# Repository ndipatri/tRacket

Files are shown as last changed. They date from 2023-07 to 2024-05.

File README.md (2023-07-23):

# tRacket

## tRacket is a mobile network-enabled device meant to be installed at a tennis court so you can know when a court is available by looking at a Twitter feed.

This outer project also involves a Kotlin Multi Platform (KMP) solution to provide mobile code for both iOS and Android.  I've recently decided that using Twitter to access live tRacket information is better.. So most of my work now on this project is inside of this subdirectory of this Github Project:

[tRacket Device Project](https://github.com/ndipatri/tRacket/blob/main/particle/workbench/tRacket/README.md)

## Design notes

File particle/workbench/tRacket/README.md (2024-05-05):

# tRacket - Tennis Court Occupancy Tracker

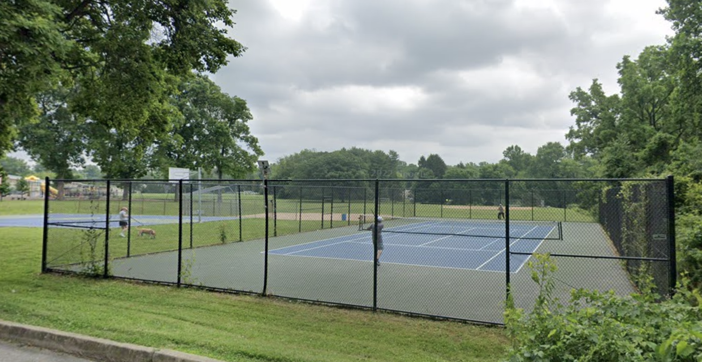
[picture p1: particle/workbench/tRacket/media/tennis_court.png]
tRacket Tennis Court


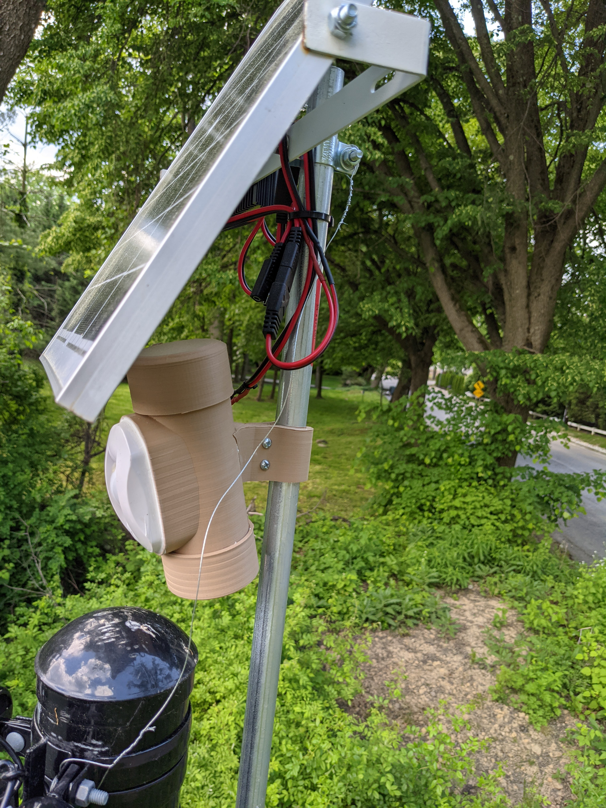
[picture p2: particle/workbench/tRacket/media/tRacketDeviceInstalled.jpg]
tRacket Device Installed


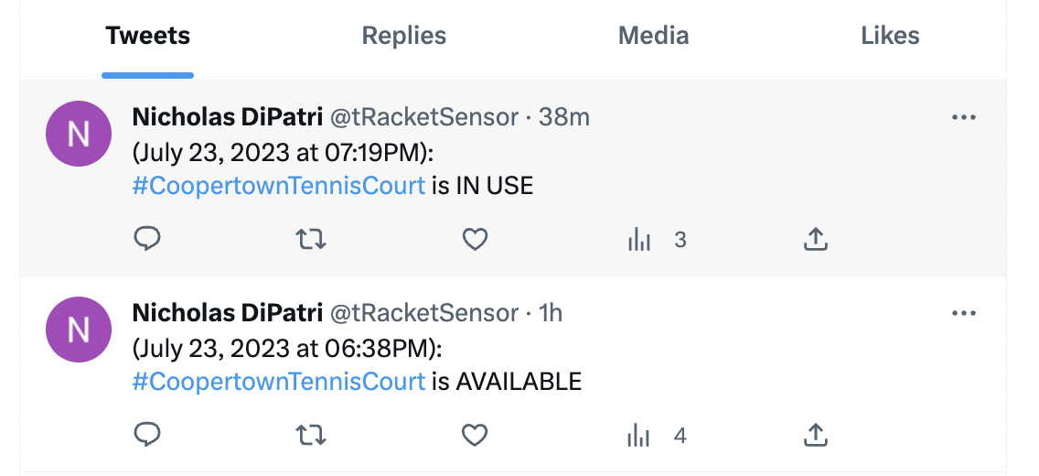
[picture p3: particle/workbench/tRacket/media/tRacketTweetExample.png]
tRacket Tweet Example


This is the Particle Workbench project that contains the code for the courtside tRacket device itself. 

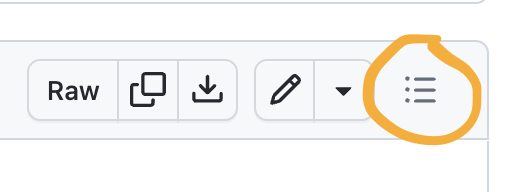
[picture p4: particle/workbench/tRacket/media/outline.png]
Turn on Outline View
I recommend viewing this README with 'Outline' view turned on: 

## Architecture

There are three main components to the tRacket system: the tRacket courtside device, an MQTT Broker provided by [Adafruit.io](https://io.adafruit.com/), and an Applet on the [If This Than That (IFTTT)](https://ifttt.com/) Integration Server.

The result is whenever the tRacket device detects the beginning or ending of court occupation, a Tweet is sent.

### tRacket courtside device

The tRacket [Particle](https://www.particle.io/devices/) microcontroller-based courtside device has an LTE wireless radio and can establish an MQTT connection to [Adafruit.io](https://io.adafruit.com/).  Whenever there is a change in occupancy on the court, a message is sent from the tRacket device in this format:

`2023/07/23 05:57:54PM	CoopertownElementary:1`

With a pattern of: |dateTime|tRacketID|:|Occupancy, 1-Occuped, 0-Available|

The tRacket device has a custom 12-volt NiHM battery pack that is charged by a solar panel (as shown in picture above).

### Adafruit.io MQTT Broker

[Adafruit.io](https://io.adafruit.com/) has a $10/month subscription service for devices that need to push data up to the cloud for asynchronous access.  Given the tRacket device is powered by solar and its only network connection is a very cheap LTE radio, we don't want end-consumers to connect directly to the tRacket device.  The Adafruit MQTT Broker is a perfect intermediary.

The tRacket device pushes data up to the 'occupancy' and 'recharge' MQTT topics.  When you push up to Adafruit.io, the topics or 'feeds' are created dynamically. So there is very little you need to configure on Adafruit.io for this to all work.

The 'occupancy' feed contains the occupancy data described previously.  The 'recharge' feed contains a message if the tRacket device gets low on power.  This would be useful for identifying if the solar panels are no longer charging the batteries affectively. 

**My single tRacket device has been running on solar power with no problems for over two years as of July 2023.**

### If This Than That (IFTTT) Integration Server

If This Than That (IFTTT) Integration Service ($60/yr for 'Pro' plan) monitors the Adafruit.io 'occupancy' feed and delivers a message to the [tRacketSensor Twitter Handle](https://twitter.com/tRacketSensor).  Here is an example message:

tRacket Tweet Example

From the above Tweet history, we can see that the court was occupied but then became available on July 23, 2023 at 06:38PM.  It remained available for 41 minutes until it became occupied again at 07:19PM.

My IFTTT account has been configured with two Applets.  The first detects a change in the Adafruit.io 'occupancy' feed and then passes that data in a webhook back to the second Applet which responds by formulating the above message and posting a Tweet.

Configuring these two Applets is rather tedious and involves the following details:

#### Two Applets are needed. ####

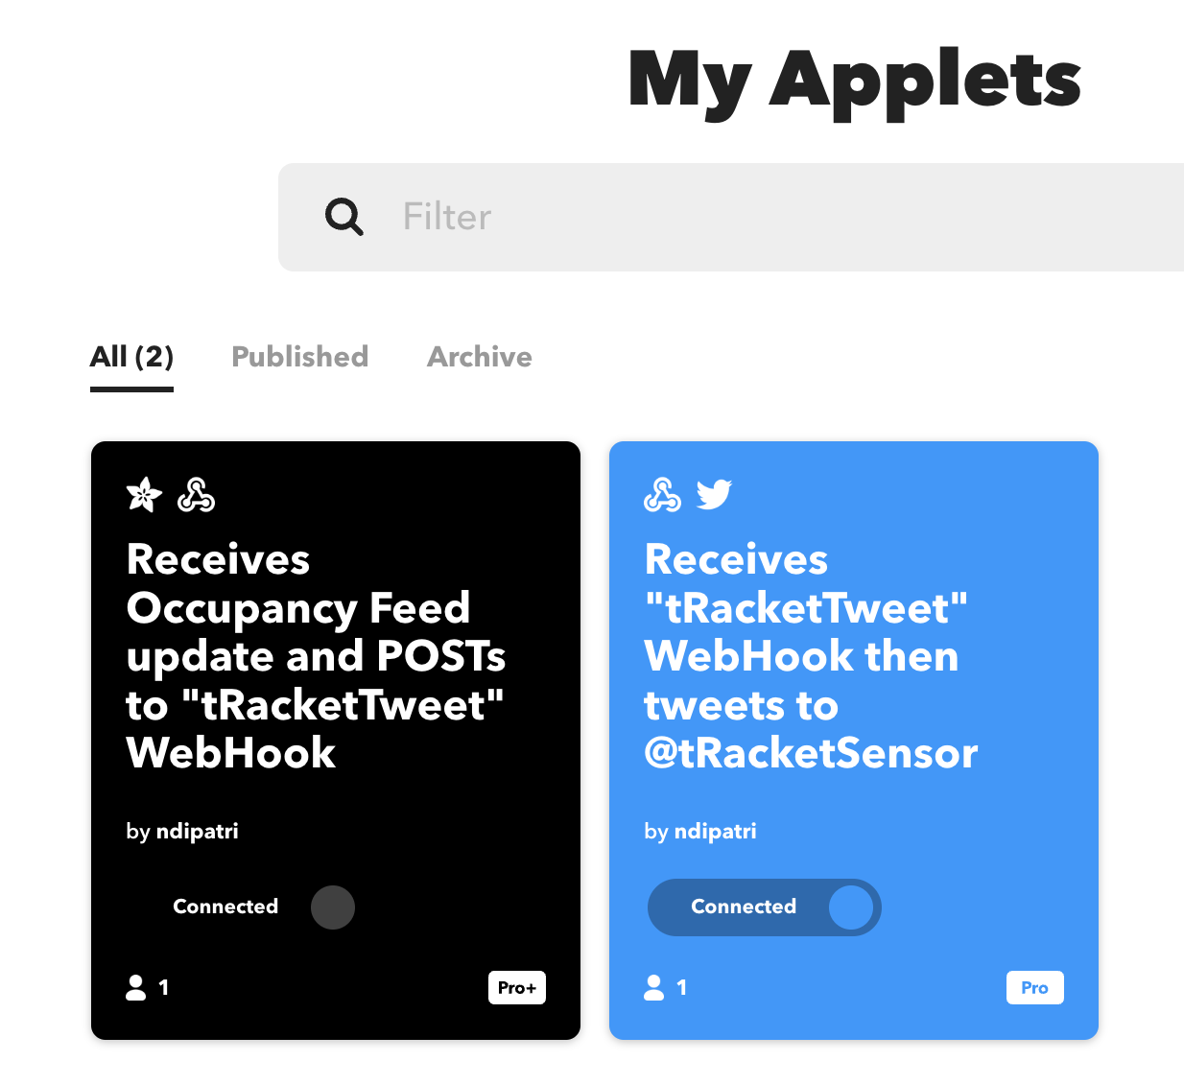
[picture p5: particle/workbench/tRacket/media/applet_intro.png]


#### First Applet ####

'Receives Occupancy Feed update and POSTs to "tRacketTweet" WebHook'

##### First Applet requires four steps: #####

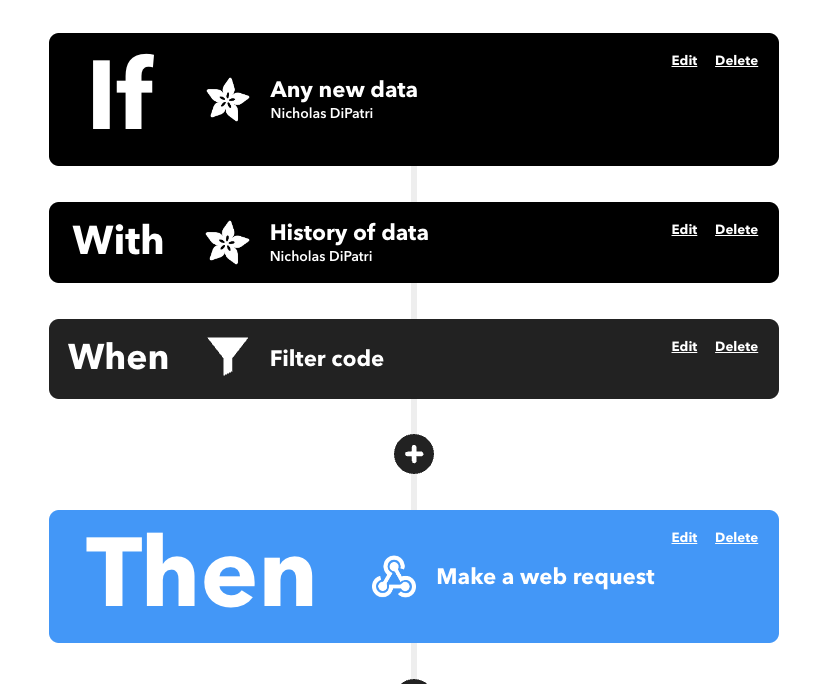
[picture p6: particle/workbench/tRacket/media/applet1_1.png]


###### First Applet, First Step. If: 'Any new data' #####

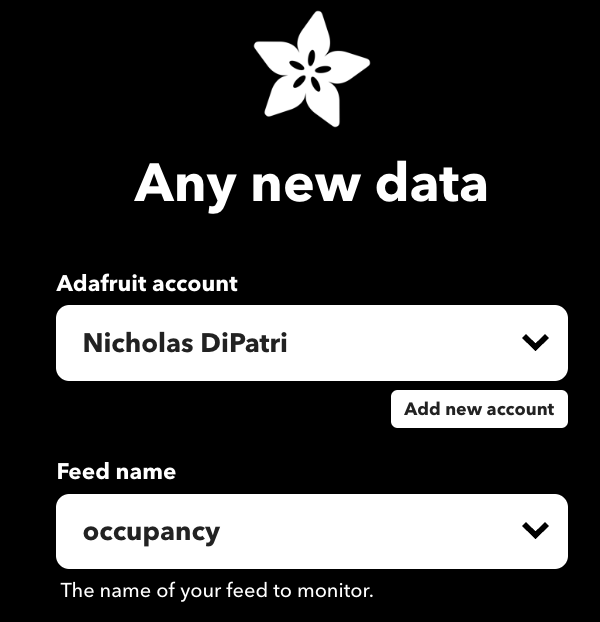
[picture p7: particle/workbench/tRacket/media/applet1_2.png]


###### First Applet, Second Step. With: 'History of data' ######

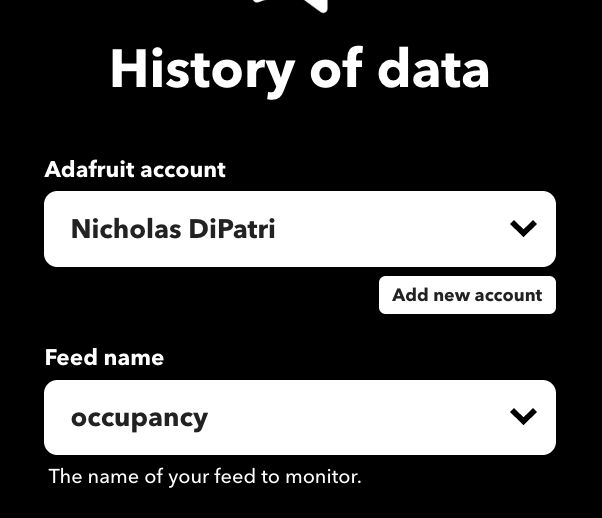
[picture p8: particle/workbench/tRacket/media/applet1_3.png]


###### First Applet, Third Step. When: 'Filter code' ######

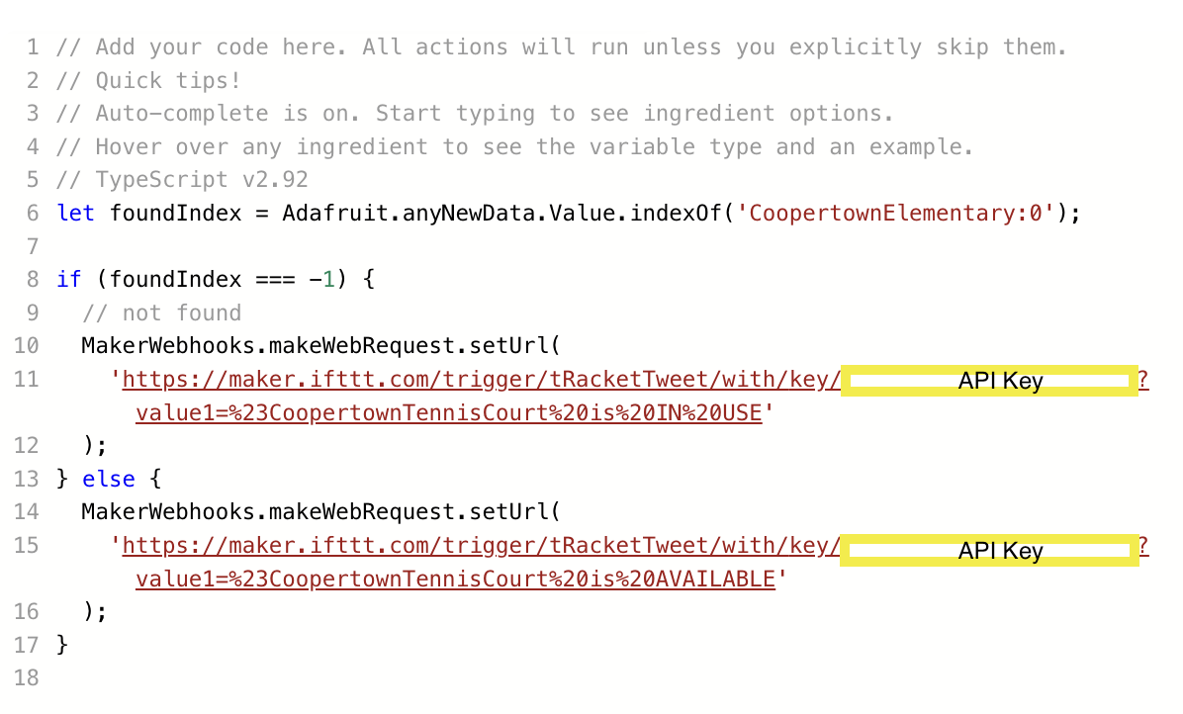
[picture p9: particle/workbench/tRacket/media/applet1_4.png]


###### First Applet, Fourth Step. Then: 'Make a web request' ######

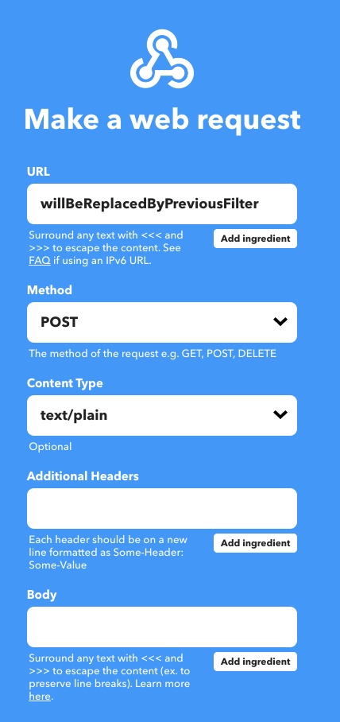
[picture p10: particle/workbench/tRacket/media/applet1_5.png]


#### Second Applet ####

'Receives "tRacketTweet" WebHook then tweets to @tRacketSensor'

##### Second Applet requires two steps: #####

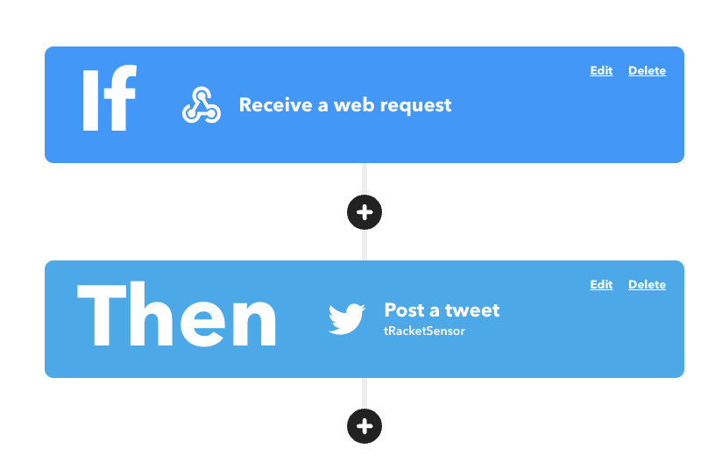
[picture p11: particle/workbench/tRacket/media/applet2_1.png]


###### Second Applet. First Step. If: 'Receive a web request' #####

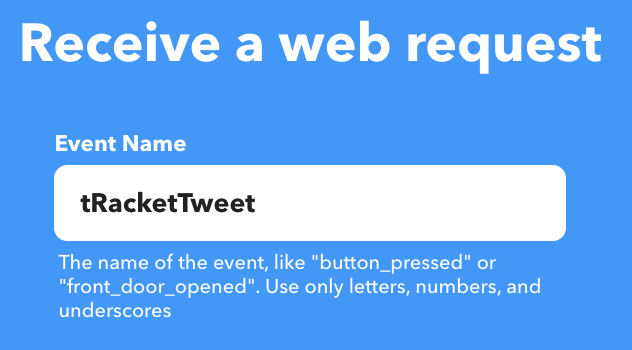
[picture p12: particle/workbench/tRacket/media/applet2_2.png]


###### Second Applet. Second Step. Then: 'Post a Tweet' ######

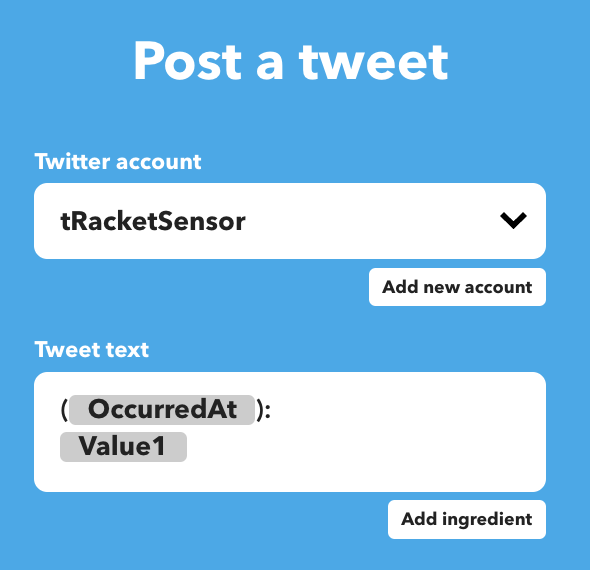
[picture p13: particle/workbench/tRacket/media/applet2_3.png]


### Parts List ###

#### 12V Solar Panel with Charging Circuit ####
I used a [Solar Panel kit](https://www.amazon.com/gp/product/B08GX19KT9/ref=ppx_yo_dt_b_search_asin_title?ie=UTF8&psc=1).  The charging terminals from the solar panel attach directly across the 12v NiMH battery pack. (+ to +, - to -)

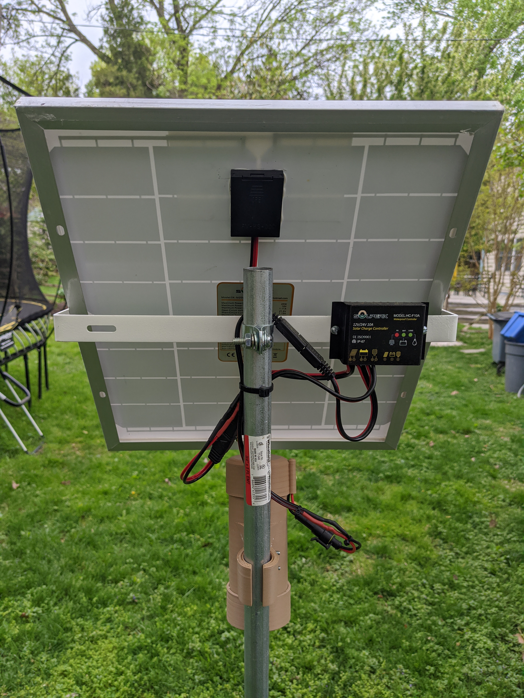
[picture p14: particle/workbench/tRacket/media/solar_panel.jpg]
solar panel


#### Rechargeable Battery Pack ####

The battery pack is custom built from [10 1.2V 2800mAH NiHM batteries](https://www.amazon.com/gp/product/B07PJZKB8X/ref=ppx_yo_dt_b_search_asin_title?ie=UTF8&psc=1).  They are soldered in series. 8 are in one pack and 2 are in another.  This arrangement was made to be able to fit the batteries most efficiently in the 3D enclosure. The 2-pack fit under the circuit board. Lots of electrical tape is used to prevent shorts anywhere.

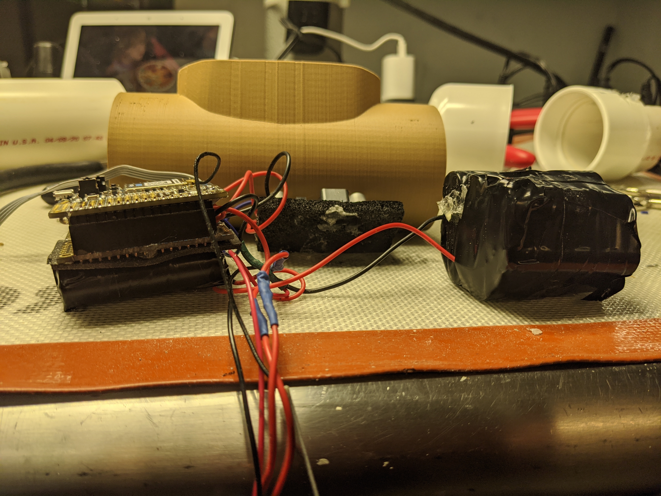
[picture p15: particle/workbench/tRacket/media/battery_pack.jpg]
battery pack


#### DC-DC Buck Converter ####

The [DC-DC Buck Converter](https://www.amazon.com/Adjustable-Converter-1-5-35v-Efficiency-Regulator/dp/B07C2QF1T1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) is what converts our 12V battery to 3.7V for the micro-controller.  It has a micro-potentiometer that is used to manually adjust down the Vout.

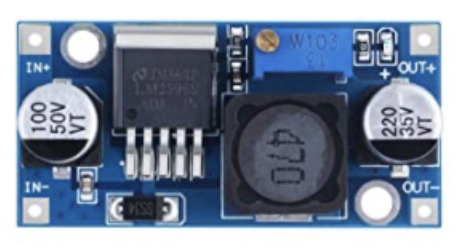
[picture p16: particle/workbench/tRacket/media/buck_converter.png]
buck converter


#### Particle Boron MicroController ####

The [Boron](https://www.amazon.com/PARTICLE-Development-Endpoints-Circuitry-Bluetooth/dp/B07N96P69L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) is a Arduino-based Microcontroller with LTE cellular network connectivity.

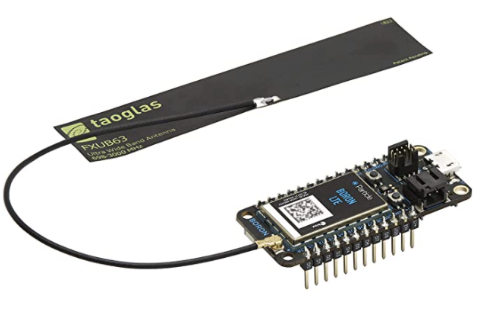
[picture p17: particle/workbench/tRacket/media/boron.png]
Boron Microcontroller


The [tRacket.ino](src/tRacket.ino) file can be used to program the Particle Boron.  You will need to create your own [Secrets.h](src/Secrets.h) file which contains the following content:

```
#ifndef SECRETS_H
#define SECRETS_H

// If you check in this code WITH this KEY defined, it will be detected by IO.Adafruit
// and IT WILL BE DISABLED!!!  So please make sure this file is 'ignored' by your
// source code management!
#define AIO_USERNAME "xxxxxx"
#define AIO_KEY "aio_xxxxx"
#define AIO_SERVER      "io.adafruit.com"
#define AIO_SERVERPORT  1883          // use 8883 for SSL

#endif
```

#### Motion Sensor (Brojen BJ-912)  ####

The [Brojen BJ-912](https://www.amazon.com/BROJEN-Brojen-BJ-912-Curtain/dp/B07C53ZS2Y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) motion sensor is placed directly inside the 3D enclosure.  This sensor requires 12V which is why we have a 12V supply. The reason I use this motion sensor device unmodified is so anyone on the court will readily identify tRacket as simply a motion sensor and not something more invasive like a camera or microphone.

Changes need to be made on the inside of the motion sensor. The 'Normally Open (NO)' jumper needs to be ~~removed~~ (jumper should now remain in the 'Normally Closed (NC)' position) and the 'LED ON' (i.e. 'Enable LED') jumper wires need to be brought outside of the sensor as shown.  The 'Enable LED' signal is set by the microcontroller as the LED is enabled when the tRacket is in 'test' mode.  This is so under normal operation, the LED is turned off.

The motion sensor should be sealed into the main 3D enclosure with exterior silicon-based caulk.  It's important to make this a waterproof seal.

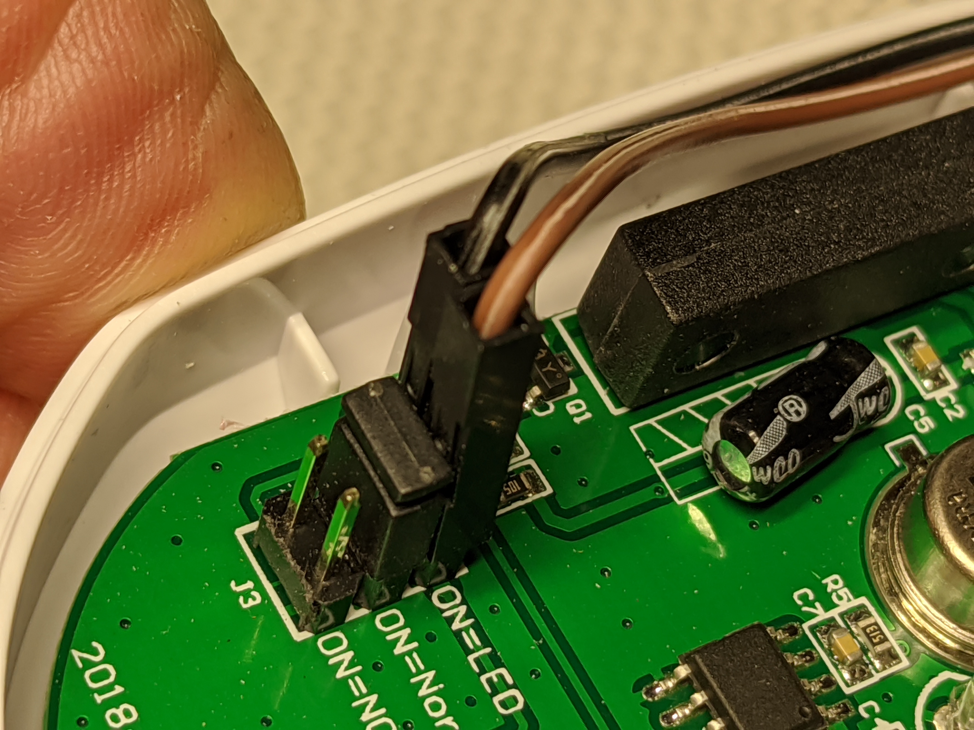
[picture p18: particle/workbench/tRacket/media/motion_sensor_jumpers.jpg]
Motion Sensor Jumpers


The 'Enable LED' signal is connected to the external bus on the motion sensor as shown:

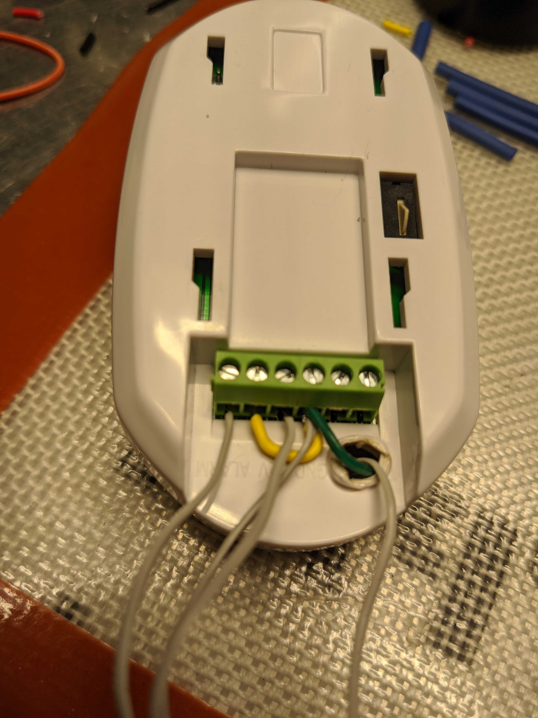
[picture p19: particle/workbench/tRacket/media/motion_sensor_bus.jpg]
Motion Sensor Bus


#### Featherwing Doubler ####

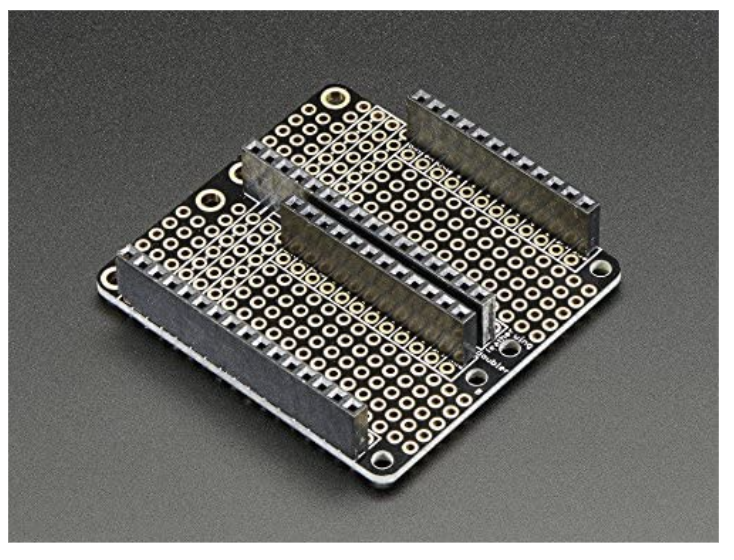
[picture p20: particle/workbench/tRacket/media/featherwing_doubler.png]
Featherwing Doubler


[Featherwing]((https://www.adafruit.com/product/2890)) is a standard for wiring up microcontrollers and peripherals.  Certain connections are common across all three sockets.  The VBAT pin has a max rating of 3.7V.  

#### Current Meter ####

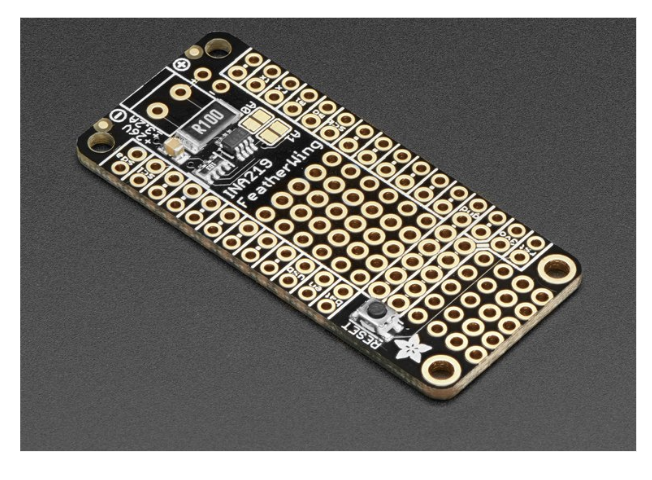
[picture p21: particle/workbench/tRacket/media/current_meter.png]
Current Meter


We use the [Adafruit INA219 FeatherWing Current Meter](https://learn.adafruit.com/adafruit-ina219-current-sensor-breakout) to warn us when the 12V battery needs to be recharged. 

This comes in the Featherwing form-factor so it fits on the above Featherwing Doubler along with the Particle microcontroller. It also has a small ‘experiment’ area onto which I install a transistor to drive the motion sensor.

We currently report one of two states: ‘RECHARGE’ or ‘GOOD’.  We employ a Schmitt Trigger to determine which state we are in.  This requires two voltage thresholds:  a low (12.2 VDC) and a high (12.6 VDC). This avoids ‘oscillating’ that might happen if the voltage were to hover around a single threshold (e.g. RECHARGE, GOOD, RECHARGE, GOOD, etc.) 

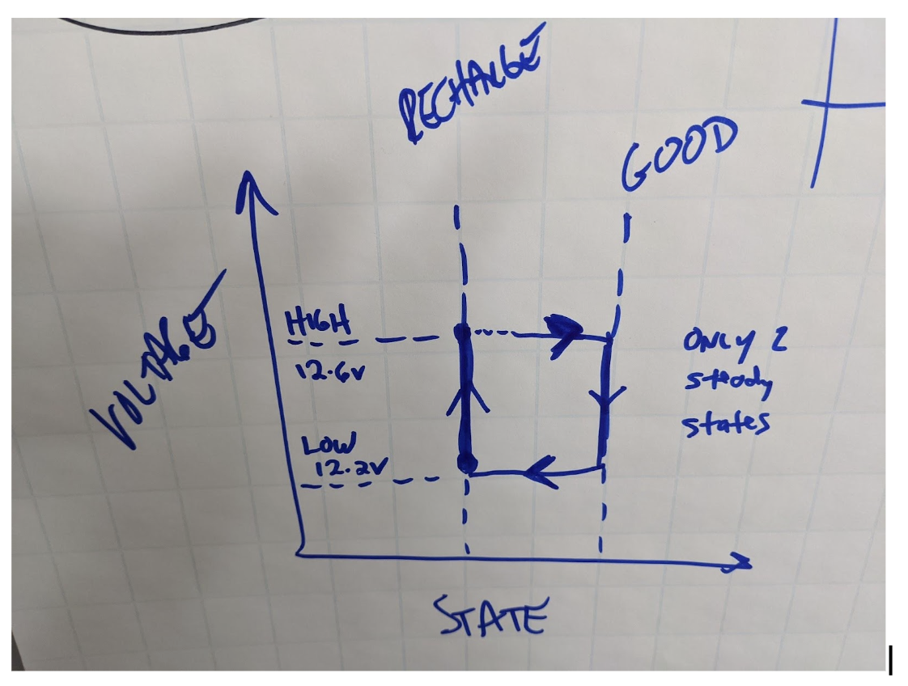
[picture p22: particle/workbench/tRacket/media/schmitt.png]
Schmitt Trigger


#### Schematic ####

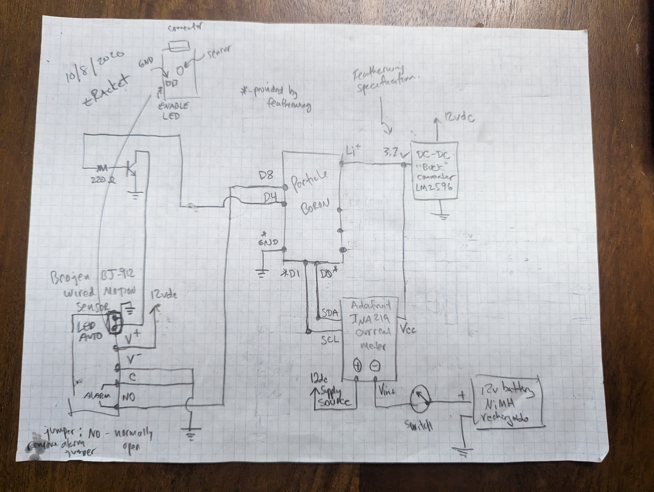
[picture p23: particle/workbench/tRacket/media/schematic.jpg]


### 3D STL Files ###

The tRacket device is built using 3D-printed parts. The tRacket device is mounted to a pole with a 3D-printed bracket.  The pole is mounted to a typical tennis court using stainless-steel band clamps.

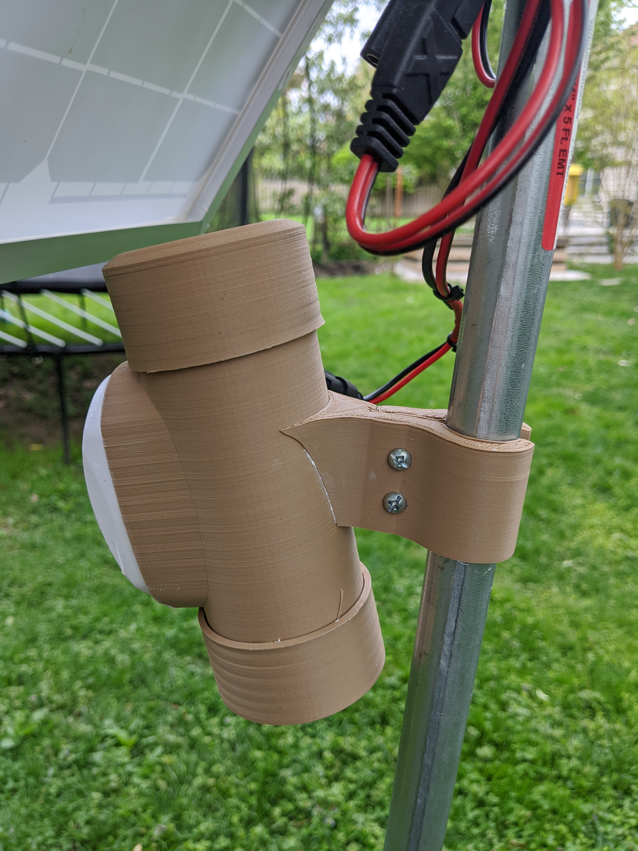
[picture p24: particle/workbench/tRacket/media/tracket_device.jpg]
tRacket Device


pole mount

[Main Body](3d_prints/tRacket_mainBody.stl)

[Body Mount Left](3d_prints/tRacket_bodyMount1.stl)

[Body Mount Right](3d_prints/tRacket_bodyMount2.stl)

[Bottom Cap](3d_prints/tRacket_bottomCap.stl)

[Top Cap](3d_prints/tRacket_topCap.stl)

[Internal Tray](3d_prints/tRacket_tray.stl)

### Assembly Instructions ###

All seals should be secured with exterior grade silicon-based caulk.  The following pictures are meant to provide guidance on how to assemble tRacket parts.

Assembly 1

Assembly 2

Assembly 3

Assembly 4

Assembly 5

Assembly 6

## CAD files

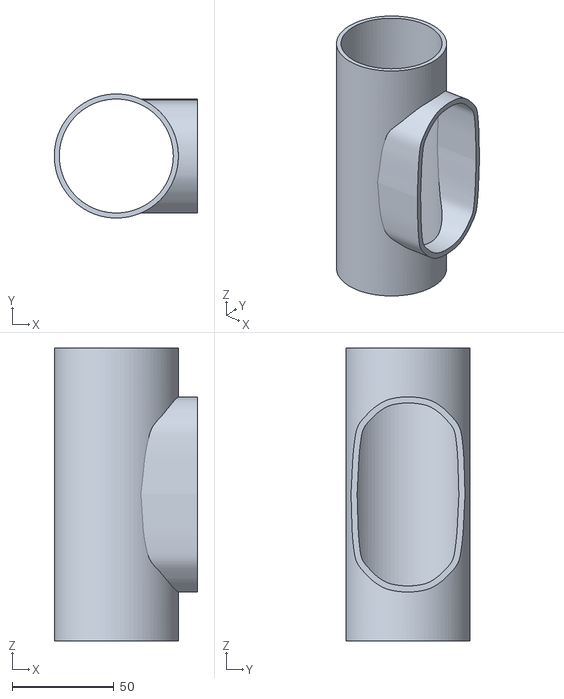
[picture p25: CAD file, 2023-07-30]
particle/workbench/tRacket/3d_prints/tRacket_mainBody.stl
70.5 x 61.0 x 144.0

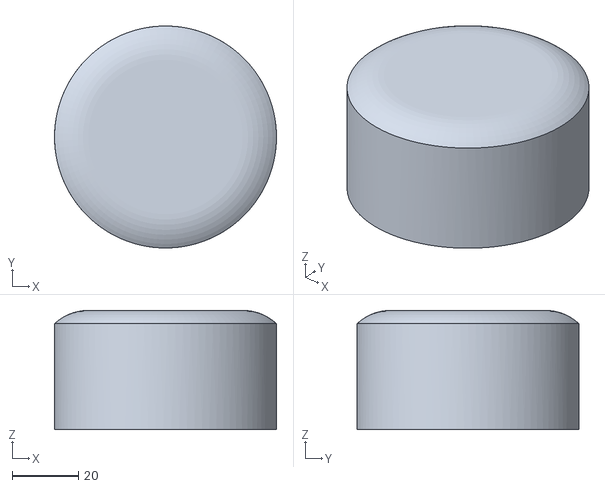
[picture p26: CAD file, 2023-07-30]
particle/workbench/tRacket/3d_prints/tRacket_bottomCap.stl
67.0 x 67.0 x 36.0

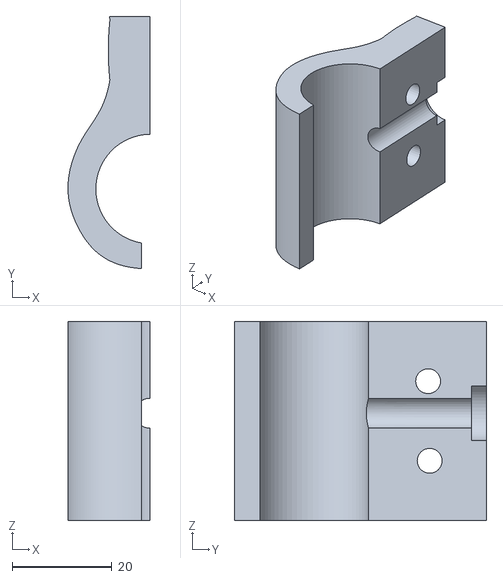
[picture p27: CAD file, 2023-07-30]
particle/workbench/tRacket/3d_prints/tRacket_bodyMount1.stl
16.5 x 50.7 x 40.0

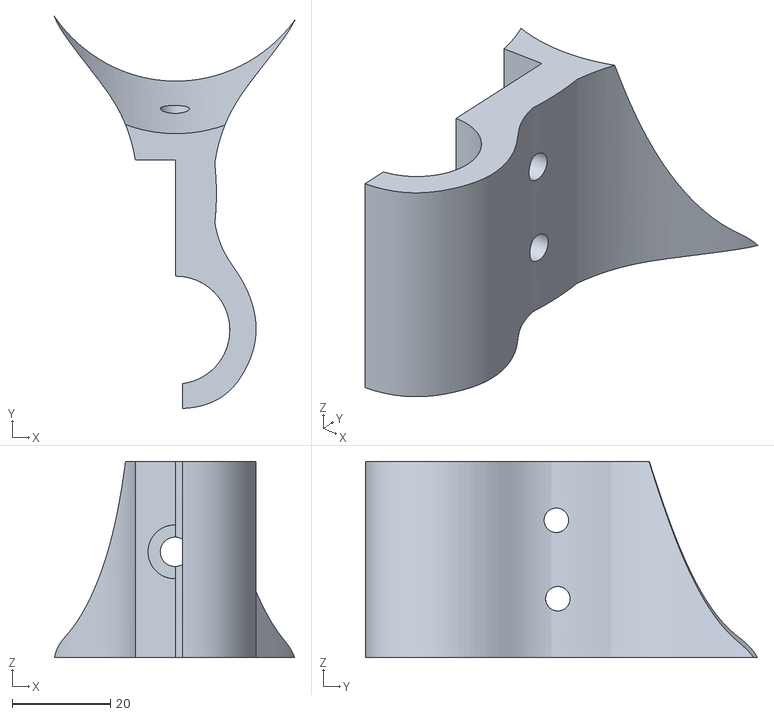
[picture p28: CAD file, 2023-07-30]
particle/workbench/tRacket/3d_prints/tRacket_bodyMount2.stl
49.0 x 80.0 x 40.0

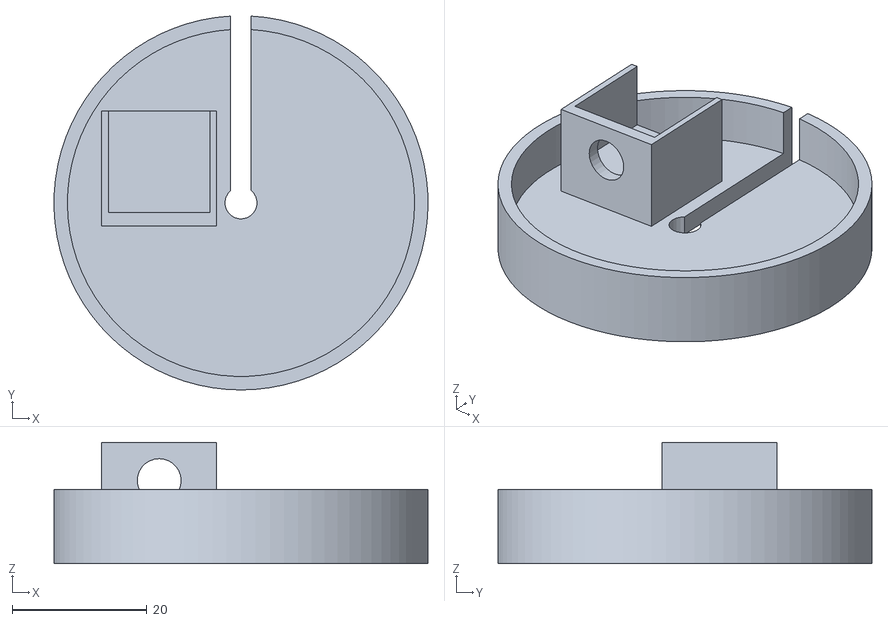
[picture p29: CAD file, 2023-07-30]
particle/workbench/tRacket/3d_prints/tRacket_tray.stl
55.5 x 55.5 x 18.0

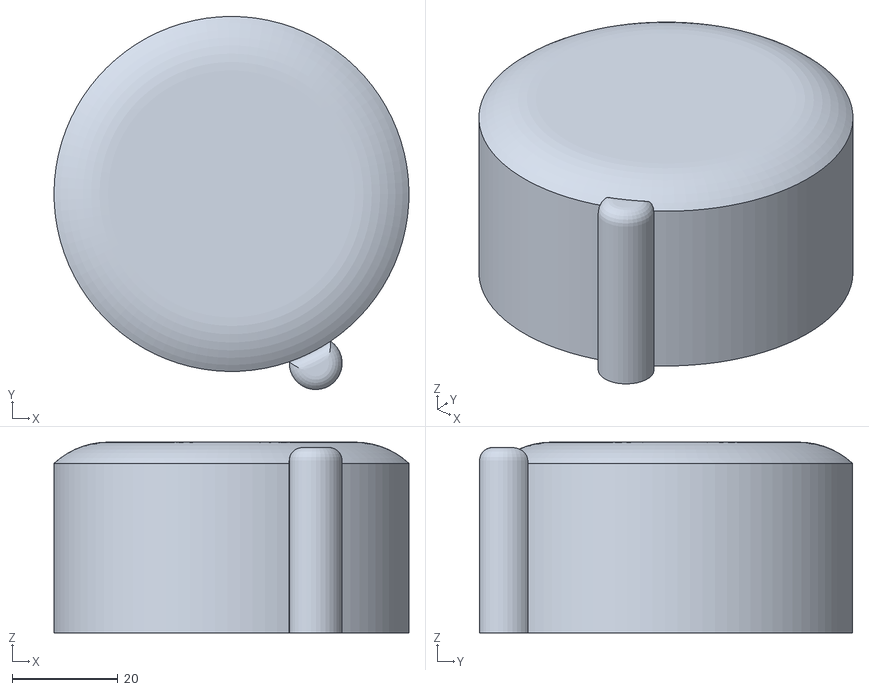
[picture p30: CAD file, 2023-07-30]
particle/workbench/tRacket/3d_prints/tRacket_topCap.stl
67.0 x 70.4 x 36.0

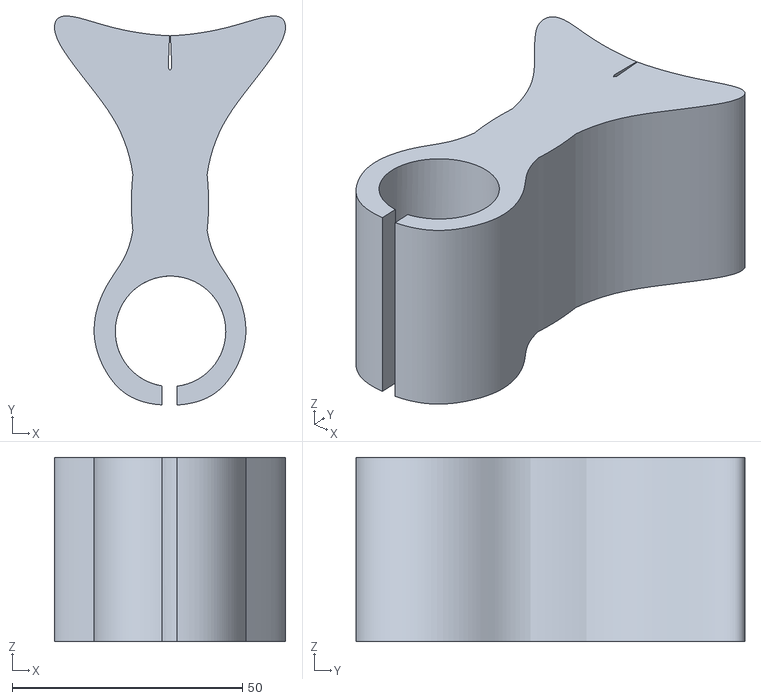
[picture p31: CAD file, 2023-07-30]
particle/workbench/tRacket/3d_prints/tRacket_poleMount.stl
50.2 x 84.5 x 40.0

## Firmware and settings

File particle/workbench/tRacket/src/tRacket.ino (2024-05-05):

#include <Adafruit_IO_Client.h>
#include "adafruit-ina219.h"
#include "Adafruit_MQTT.h"
#include "Adafruit_MQTT_SPARK.h"
#include "DeviceNameHelperRK.h"
#include "Secrets.h"

// The current meter we will use to determine when battery needs to be
// recharged.
Adafruit_INA219 powerMeter;

// This can be retrieved from https://io.adafruit.com/ndipatri/profile
// (or if you aren't ndipatri, you can create an account for free)

TCPClient client; // TCP Client used by Adafruit IO library


Adafruit_MQTT_SPARK mqtt(&client, AIO_SERVER, AIO_SERVERPORT, AIO_USERNAME, AIO_KEY);

String mqttOccupancyTopicName = String(AIO_USERNAME) + "/feeds/occupancy"; 
Adafruit_MQTT_Publish occupancyMQTTTopic = Adafruit_MQTT_Publish(&mqtt,  mqttOccupancyTopicName);

String mqttRechargeTopicName = String(AIO_USERNAME) + "/feeds/recharge"; 
Adafruit_MQTT_Publish rechargeMQTTTopic = Adafruit_MQTT_Publish(&mqtt,  mqttRechargeTopicName);

Adafruit_MQTT_Subscribe errors = Adafruit_MQTT_Subscribe(&mqtt, String(AIO_USERNAME) + "/errors");
Adafruit_MQTT_Subscribe throttle = Adafruit_MQTT_Subscribe(&mqtt, String(AIO_USERNAME) + "/throttle");

int MOTION_SENSOR_DETECTED_INPUT_PIN = D8; 
int MOTION_SENSOR_LED_ENABLE_OUTPUT_PIN = D4; 

// How long we keep the device in test mode after startup
long STARTUP_TEST_MODE_PERIOD_MINUTES = 15;
long testModeStartTimeMillis = -1;

// We want to indicate when we are actively listening to sensor input
int MOTION_LISTENING_LED_OUTPUT_PIN = D7; 

// We need a HIGH and LOW value to implement a 'Schmitt Trigger' for
// voltage measurement.  Otherwise, we get oscilation of value around
// a single threshold.
float BATTERY_CHARGE_THRESHOLD_VOLTS_HIGH = 12.4;
float BATTERY_CHARGE_THRESHOLD_VOLTS_LOW = 11.9;

bool batteryNeedsCharging = false;
double batteryVoltageLevel = 0.0;

// If a monitored value is triggered we latch it for this time period so
// external monitors have time to capture it
//
// This also has the effect of maintaining the 'occupied' state for the entire
// duration a court is in use... it's a sort of low-pass filter
long MOTION_PERIOD_INTERVAL_MINUTES = 6;

long lastMotionTimeMillis = -1L;

long MOTION_POLL_DURATION_MINUTES = 3;

// the ratio of motion hits to missed during a motion check interval
float MOTION_RATIO_THRESHOLD = .08;

bool firstPass = true;

// For deviceName retrieval and storage
SYSTEM_THREAD(ENABLED);

int SLEEP_START_HOUR = 21; // 9pm
int SLEEP_STOP_HOUR = 6; // 6am duh.

// Keeps track of the last time we synchronized our wall clock with
// the server
int lastClockSyncMillis = 0;

void setup() {
    
    Serial.begin(115200);

    // This helps with retrieving Device name
    DeviceNameHelperEEPROM::instance().setup(100);
    DeviceNameHelperEEPROM::instance().withCheckPeriod(24h);

    // By default, LED on OFF when motion is triggered
    pinMode(MOTION_SENSOR_LED_ENABLE_OUTPUT_PIN, OUTPUT);
    digitalWrite(MOTION_SENSOR_LED_ENABLE_OUTPUT_PIN, LOW);

    powerMeter.begin();
    powerMeter.setCalibration_16V_400mA();

    Particle.variable("minutesSinceLastMotion", minutesSinceLastMotion);
    Particle.variable("batteryVoltageLevel", batteryVoltageLevel);
    Particle.variable("isInTestMode", isInTestMode);

    Particle.function("turnOnTestMode", turnOnTestMode);
    Particle.function("turnOffTestMode", turnOffTestMode);

    pinMode(MOTION_SENSOR_DETECTED_INPUT_PIN, INPUT_PULLUP);
    pinMode(MOTION_LISTENING_LED_OUTPUT_PIN, OUTPUT);

    stopMotionPeriod();

    // NJD TODO - If this were to move elsewhere, we could support something more
    // dynamic.. but this is ok for now.
    // Set time zone to Eastern USA daylight saving time
    Time.zone(-4);

    // We always enter test mode upon startup and we want to expire
    // that particular test session
    turnOnTestMode("");

    sendUnOccupiedToCloud();
}




void loop() {

    if (handleIncorrectDevice()) {
        return;
    }
    
    // so everyone knows we're awake!
    digitalWrite(MOTION_LISTENING_LED_OUTPUT_PIN, HIGH);

    // Check to see if we know ou device name yet...
    DeviceNameHelperEEPROM::instance().loop();

    // We need an accurate clock for when we go to sleep
    // NJD Disabling thing temporarily as I try to track down what's 
    // causing device to have issues...
    //syncWallClock();

    if (!deviceNameFound()) {
        sleepForSeconds(120);

        publishParticleLog("error", "cantFindDeviceNameSleeping...");

        return;
    }

    // this can take minutes to execute
    if (checkForMotion()) {
        publishParticleLog("activityReport", "motionDetected");

        if (!currentlyInMotionPeriod()) {

            // Starting new motion period
            publishParticleLog("activityReport", "startMotionPeriod(" + String(getDeviceName()) + ")");
            sendOccupiedToCloud();
        }

        // Detecting motion either starts or extends our current motion period
        startMotionPeriod();
    } else {

        // no current motion.. see if our motion period has expired yet...
        if (hasMotionPeriodExpired()) {

            stopMotionPeriod();

            publishParticleLog("activityReport", "endMotionPeriod(" + String(getDeviceName()) + ")");
            sendUnOccupiedToCloud();
        }
    }

    checkBattery(firstPass);
    firstPass = false;

    expireStartupTestModeIfNecessary();

    // so everyone knows we're going to sleep!
    digitalWrite(MOTION_LISTENING_LED_OUTPUT_PIN, LOW);

    sleepForSeconds(2);
}




// this can take minutes to execute
bool checkForMotion() {
    long pollIntervalStartTimeMillis = millis();

    int motionTriggerCount = 0;
    int numberOfPollIntervals = 0;

    // check for a bit of time
    while((millis() - pollIntervalStartTimeMillis) < (MOTION_POLL_DURATION_MINUTES*60000)) {

        numberOfPollIntervals++;

        // sensor configured NC (normally closed).. so it goes HIGH
        // when it's triggered
        if (digitalRead(MOTION_SENSOR_DETECTED_INPUT_PIN) == HIGH) {
            publishParticleLog("activityReport", "MOTION DETECTED");

            motionTriggerCount++;
        }

        // when triggered, motion sensor only indicates for 3 seconds...
        // so our poll interval has to be at least twice as fast (Nyquist Interval!)
        delay(1000);
    }

    float motionDetectedAverage = (float)motionTriggerCount/numberOfPollIntervals;

    publishParticleLog("motionCheckDone", "motionAvg:" + String(motionDetectedAverage));

    return motionDetectedAverage > MOTION_RATIO_THRESHOLD;
}

bool handleIncorrectDevice() {
    if (PLATFORM_ID != PLATFORM_ARGON && PLATFORM_ID != PLATFORM_BORON) {
        Particle.publish("TERMINAL", "Must be run on Argon or Boron", 60, PUBLIC);

        sleepForSeconds(60);

        return true;
    }

    return false;
}

void sleepForSeconds(int seconds) {
    publishParticleLog("activityReport", "sleep");
    delay(seconds * 1000);
    publishParticleLog("activityReport", "awake");
}

bool shouldBeAsleepForNight() {
    int currentHour = Time.hour();

    return ((currentHour >= SLEEP_START_HOUR) ||
            (currentHour < SLEEP_STOP_HOUR));
}

void syncWallClock() {
    // manage wall clock.. since this device runs constantly, its clock can
    // drift.
    if (millis() - lastClockSyncMillis > 1000 * 60 * 60 * 24) { // once a day
        // Request time synchronization from the Particle Device Cloud
        publishParticleLog("syncWallClock", "syncTime!");
        Particle.syncTime();
        lastClockSyncMillis = millis();
    }
}

bool deviceNameFound() {
    return DeviceNameHelperEEPROM::instance().hasName();
}

char const* getDeviceName() {
    return DeviceNameHelperEEPROM::instance().getName();
}

void expireStartupTestModeIfNecessary() {
    if (isInTestMode() &&
        millis() - testModeStartTimeMillis > (STARTUP_TEST_MODE_PERIOD_MINUTES * 60000)) {

        publishParticleLog("activityReport", "endStartupTestMode");

        turnOffTestMode("");
    }
}

void sendOccupiedToCloud() {
    sendMessageToCloud(String(getDeviceName()) + ":1", &occupancyMQTTTopic);
}

void sendUnOccupiedToCloud() {
    sendMessageToCloud(String(getDeviceName()) + ":0", &occupancyMQTTTopic);
}

void sendBatteryStatusToCloud(bool batteryNeedsCharging, float batteryVoltageLevel) {

    String message = String(getDeviceName()) + ":" + (batteryNeedsCharging ? "RECHARGE" : "GOOD") + String("(") + String(batteryVoltageLevel) + String(")");

    sendMessageToCloud(message, &rechargeMQTTTopic);
}

void sendMessageToCloud(const char* message, Adafruit_MQTT_Publish* topic) {
    MQTTConnect();

    if (topic->publish(message)) {
        publishParticleLog("mqtt", "Message SUCCESS (" + String(message) + ").");
    } else {
        publishParticleLog("mqtt", "Message FAIL (" + String(message) + ").");
    }

    // this is our 'wait for incoming subscription packets' busy subloop
    // try to spend your time here
    Adafruit_MQTT_Subscribe *subscription;
    while ((subscription = mqtt.readSubscription(5000))) {
        if(subscription == &errors) {
            publishParticleLog("mqtt", "Error: (" + String((char *)errors.lastread) + ").");
        } else if(subscription == &throttle) {
            publishParticleLog("mqtt", "Throttle: (" + String((char *)throttle.lastread) + ").");
        }
    }

    MQTTDisconnect();
}


void MQTTConnect() {
    int8_t ret;

    // Stop if already connected.
    if (mqtt.connected()) {
        return;
    }

    while ((ret = mqtt.connect()) != 0) { // connect will return 0 for connected
        publishParticleLog("mqtt", "Retrying MQTT connect from error: " + String(mqtt.connectErrorString(ret)));
        mqtt.disconnect();
        delay(5000);  // wait 5 seconds
    }
}

void MQTTDisconnect() {
    mqtt.disconnect();
}

void startMotionPeriod() {
    lastMotionTimeMillis = millis();
}

void stopMotionPeriod() {
    lastMotionTimeMillis = -1L;
}

bool currentlyInMotionPeriod() {
    return lastMotionTimeMillis > 0;
}

bool hasMotionPeriodExpired() {
    return currentlyInMotionPeriod() &&
           ((millis() - lastMotionTimeMillis) > (MOTION_PERIOD_INTERVAL_MINUTES * 60000));
}

int minutesSinceLastMotion() {
    return (int)((millis() - lastMotionTimeMillis)/60000L);
}

void checkBattery(bool forceSendUpdate) {
    float shuntvoltage = powerMeter.getShuntVoltage_mV();
    float busvoltage = powerMeter.getBusVoltage_V();
    batteryVoltageLevel = busvoltage + (shuntvoltage / 1000);

    // We implement a Schmitt Trigger.  The two thresholds prevent 'oscillating'
    // that occurs with a single threshold.
    bool currentBatteryNeedsCharging = batteryNeedsCharging;

    if (batteryNeedsCharging && (batteryVoltageLevel > BATTERY_CHARGE_THRESHOLD_VOLTS_HIGH)) {
        currentBatteryNeedsCharging = false;
    }

    if (!batteryNeedsCharging && (batteryVoltageLevel < BATTERY_CHARGE_THRESHOLD_VOLTS_LOW)) {
        currentBatteryNeedsCharging = true;
    }

    if (forceSendUpdate || (currentBatteryNeedsCharging != batteryNeedsCharging)) {
        batteryNeedsCharging = currentBatteryNeedsCharging;

        sendBatteryStatusToCloud(batteryNeedsCharging, batteryVoltageLevel);
    }
}

int turnOnTestMode(String _na) {

    Particle.publish("config", "testMode turned ON", 60, PUBLIC);
    digitalWrite(MOTION_SENSOR_LED_ENABLE_OUTPUT_PIN, HIGH);

    testModeStartTimeMillis = millis();

    return 1;
}

int turnOffTestMode(String _na) {

    Particle.publish("config", "testMode turned OFF", 60, PUBLIC);
    digitalWrite(MOTION_SENSOR_LED_ENABLE_OUTPUT_PIN, LOW);

    return 1;
}

bool isInTestMode() {
    return digitalRead(MOTION_SENSOR_LED_ENABLE_OUTPUT_PIN) == HIGH;
}

void publishParticleLog(String group, String message) {
    if (PLATFORM_ID == PLATFORM_ARGON || isInTestMode()) {
        Particle.publish(group, message, 60, PUBLIC);
    }
}

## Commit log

2020-12-26 Moving arduino code into project.
2020-12-27 Tweak accelerometer tamper threshold to remove false triggers.
2020-12-28 Final Proof of Concept for Arduino code.. Settled on naming convention for Adafruit IO feeds.
2021-01-09 battery tweaks.
2021-01-12 Fixed schmitt trigger implementation for recharge indication.
    [tRacket.ino]
2021-02-28 Added 'motion test' feature so the 'motion detected' LED can be enabled/disabled.
2021-03-12 Removing tamper and starting work on low pass filter.
2021-03-14 Fixed logging.. Startup test mode now automatically ends after 15 minutes.
    [tRacket.ino]
2021-03-18 Combined feed shared by all tRacket devices...
2021-04-04 Overhaul... 1. All communications with AdafruitIO now over MQTT (to get rid of that annoying HTTP error). 2. Added error/throttle subscriptions for MQTT 3. Refactored all code to make it more readabl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
    [tRacket.ino]
2021-04-04 remove key before checkin.. Need to do a local prop substitute eventually but ok for now.
2021-04-05 Fixed small bug where it was sending unoccupied every 30 minutes during the night.
    [tRacket.ino]
2021-08-23 Remove nighttime sleep as it's not really needed. The solar panels provide plenty of power.. and the sleep mode on rare occasion seems to lock-up the device.
2021-09-17 temporarily turning off wall clock sync to see if it helps with stability.
    [tRacket.ino]
2021-10-31 More work to try and fix intermittent issue...
    Switched to EEPROM name retension and also now sends unoccupied on startup by default.
    [tRacket.ino]
2022-07-17 starting to fix LPF for motion
    [tRacket.ino]
2024-05-05 adjustment to use the stock NC configuration of IR sensor.
2024-05-05 Update README.md
    updating to indicate that we use the motion sensor in its default NC position.
